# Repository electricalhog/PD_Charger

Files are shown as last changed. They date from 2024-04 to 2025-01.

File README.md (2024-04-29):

# PD_Charger

*Schematic*
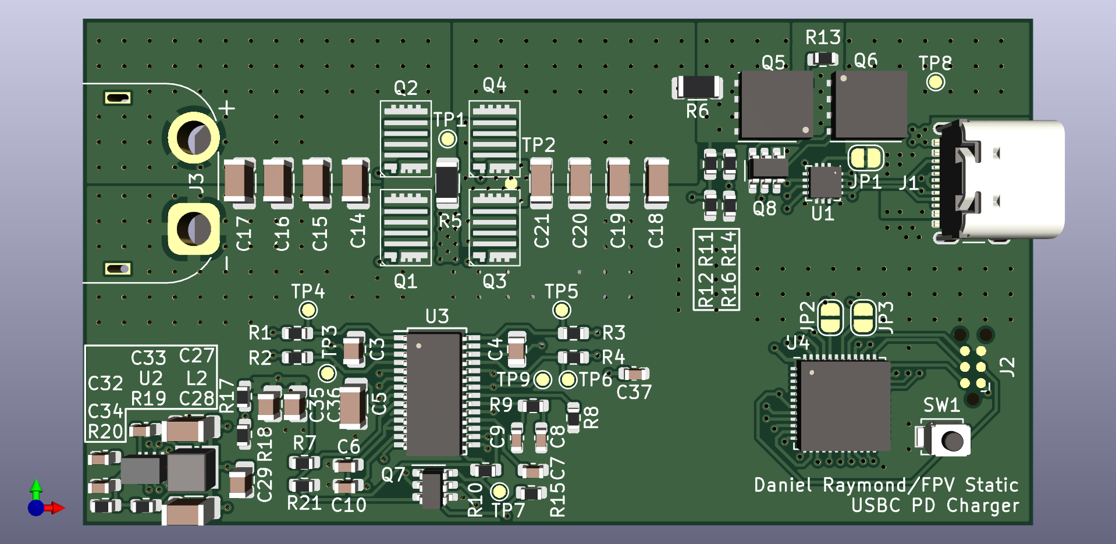
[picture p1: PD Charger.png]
PD Charger

*Board rendering*

[Digi-Key Cart](https://www.digikey.com/short/v39zppv0)

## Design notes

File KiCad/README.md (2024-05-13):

# PD_Charger
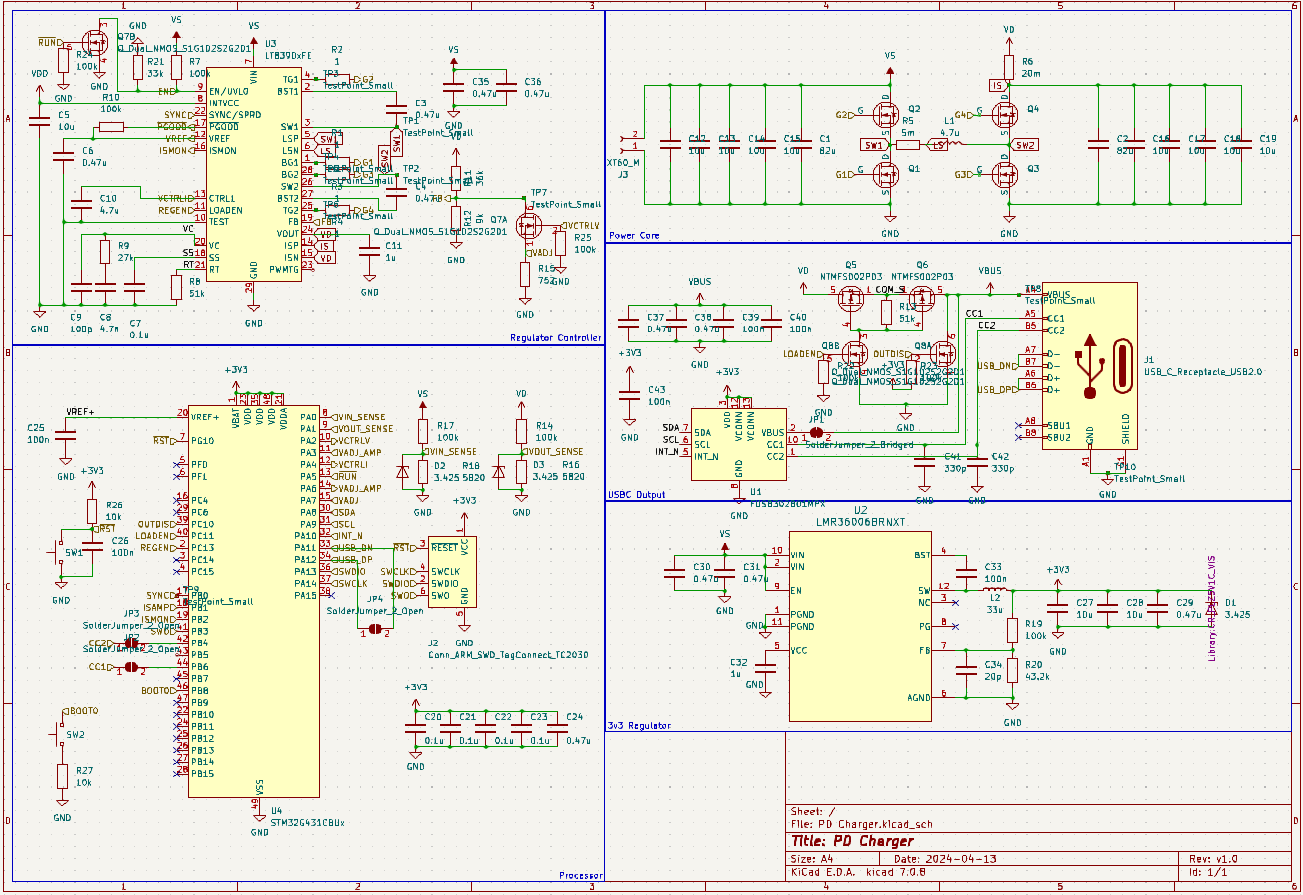
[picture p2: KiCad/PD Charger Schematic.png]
https://github.com/electricalhog/PD_Charger/blob/main/KiCad/PD%20Charger%20Schematic.png

*Schematic*
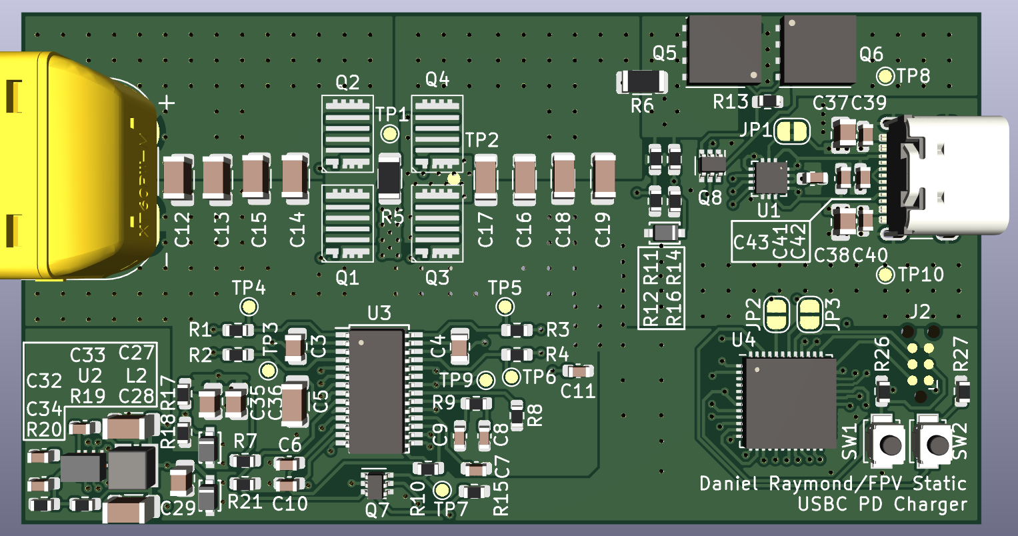
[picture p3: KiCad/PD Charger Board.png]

*Board rendering*

[Digi-Key Cart](https://www.digikey.com/short/v39zppv0)

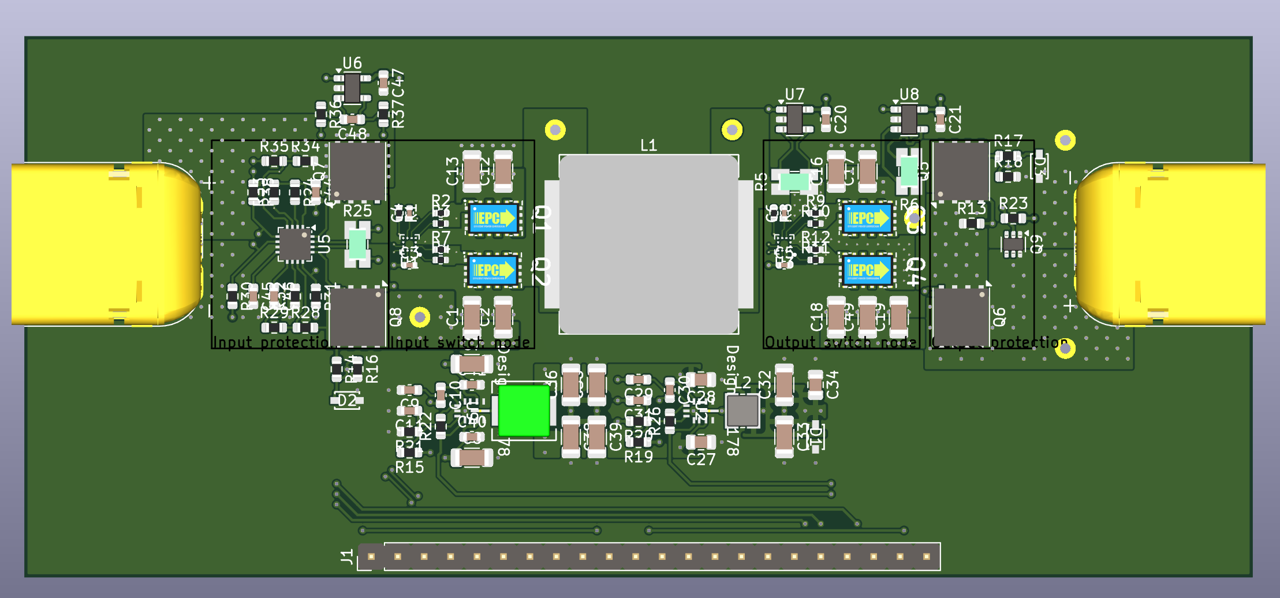
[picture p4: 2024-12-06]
KiCad/board.png

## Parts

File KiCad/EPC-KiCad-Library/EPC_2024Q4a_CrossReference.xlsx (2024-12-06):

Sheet: CrossRef
PART NUMBER | LandPattern Code | VALUE
EPC2001C | D0188 | 100V 7mE 36A
EPC2007C | D0199 | 100V 30mE 6A
EPC2010C | D0309 | 200V 25mE 22A
EPC2012C | D0375 | 200V 100mE 5A
EPC2014C | D0199 | 40V 16mE 10A
EPC2015C | D0188 | 40V 4mE 53A
EPC2016C | D0155 | 100V 16mE 18A
EPC2019 | D0364 | 200V 50mE 8.5A
EPC2020 | D0232 | 60V 2.2mE 90A
EPC2021 | D0232 | 80V 2.5mE 90A
EPC2022 | D0232 | 100V 3.2mE 90A
EPC2023 | D0232 | 30V 1.45mE 90A
EPC2024 | D0232 | 40V 1.5mE 90A
EPC2029 | D0386 | 80V 3.2mE 48A
EPC2030 | D0386 | 40V 2.4mE 48A
EPC2031 | D0386 | 60V 2.6mE 48A
EPC2032 | D0386 | 100V 4mE 48A
EPC2033 | D0386 | 150V 7mE 48A
EPC2034C | D0386 | 200V 8mE 48A
EPC2035 | D0353 | 60V 45mE 1.7A
EPC2036 | D0353 | 100V 73mE 1.7A
EPC2037 | D0353 | 100V 550mE 1.7A
EPC2038 | D0353 | 100V 3300mE 0.5A
EPC2039 | D0144 | 80V 25mE 6.8A
EPC2040 | D0210 | 15V 30mE 3.4A
EPC2044 | D0265 | 100V 9.4A 10.5mE
EPC2045 | D0012 | 100V 7mE 16A
EPC2050 | D0078 | 350V 65mE 6.3A
EPC2051 | D0001 | 100V 25mE 1.7A
EPC2052 | D0045 | 100V 13.5mE 8.2A
EPC2053 | D0034 | 100V 3.8mE 48A
EPC2054 | D0474 | 200V 32mE 2.4A
EPC2055 | D0133 | 40V 29A 3.6mE
EPC2057 | D0870 | 50V 8.5mE 6.9A
EPC2059 | D0298 | 170V 24A 6.8mE
EPC2065 | D0320 | 80 V 60A 3.6mE
EPC2066 | D0650 | 40V 1.1mE 90A
EPC2067 | D0540 | 40V 1.55mE 69A
EPC2069 | D0496 | 40V 2.25mE 80A
EPC2070 | D0562 | 100V 23mE 1.7A
EPC2071 | D0683 | 100V 2.2mE 64A
EPC2088 | D0320 | 100 V 60A 3.2mE
EPC2100 | D0342 | 30V 8.2mE/2.1mE 10A/40A 1:4HB
EPC2101 | D0342 | 60V 11.5mE/2.8mE 10A/40A 1:4HB
EPC2102 | D0342 | 60V 4.9mE 30A 1:1HB
EPC2103 | D0342 | 80V 5.5mE 30A 1:1HB
EPC2104 | D0342 | 100V 6.8mE 30A 1:1HB
EPC2105 | D0342 | 80V 14.5mE/3.6mE 10A/40A 1:4HB
EPC2106 | D0144 | 100V 70mE 1.7A 1:1HB
EPC2107 | D0144 | 100V 390mE 1.7A 1:1HB
EPC2108 | D0144 | 60V 240mE 1.7A 1:1HB
EPC2110 | D0144 | 120V 110mE 3.4A 1:1Common Source
EPC2111 | D0331 | 30 V HB 19mE/8mE 16A/16A 1:2HB
EPC2121 | D0826T44M | 100V 50mE 2.5A bi-directional
EPC2152 | D0122 | 80V, 12mE Sym HB IC with UVLO & ESDs.
EPC21601 | D0452 | 40V 10A eToF Laser Driver IC, 5V VDD 3.3V logic in
EPC21603 | D0452 | 40V 10A eToF Laser Driver IC, 5V VDD LVDS logic in
EPC21701 | D0617 | 80V 15A eToF Laser Driver IC, 3.3V VDD logic in
EPC2202 | D0155 | 80V 17mE 18A
EPC2203 | D0353 | 80V 80mE 1.7A
EPC2204 | D0133 | 100V 32A 6mE
EPC2204A | D0133 | 80V 29A 6mE
EPC2206 | D0232 | 80V 2.2mE 90A
EPC2207 | D0177 | 200V 22mE 22A
EPC2212 | D0155 | 100V 40mE 10A
EPC2214 | D0166 | 80V 20mE 10A
EPC2215 | D0111 | 200V 42A 8mE
EPC2216 | D0210 | 15V 26mE 3.4A
EPC2218 | D0320 | 100 V 60A 3.2mE
EPC2218A | D0320 | 80V 60A 3.2mE
EPC2219 | D0353 | 65 V, 3300mE, 0.5A
EPC2221 | D0551 | 100V 59mE 5A
EPC2234 | D0386 | 160V 8mE 48A
EPC2252 | D0045 | 100V 11mE 8.2A
EPC2302 | D0606F | 100V 101A 1.9mE
EPC2304 | D0606F | 200V 102 5mE
EPC2305 | D0606F | 150V 80A 3mE
EPC2306 | D0606H | 100V 48A 3.8mE
EPC2307 | D0606H | 200V 48A 10mE
EPC2308 | D0606H | 150V 48A 6mE
EPC23101 | D0629 | 100V, 2.7mE Upper FET HB driver IC with UVLO & ESDs.
EPC23102 | D0727 | 100V, 30A, 6.6mE Sym HB IC with UVLO & ESDs.
EPC23103 | D0727m | 100V, 30A, 8.3mE Sym HB IC with UVLO & ESDs.
EPC23104 | D0727u | 100V, 30A, 11mE Sym HB IC with UVLO & ESDs.
EPC2619 | D0133 | 80V 29A 4mE
EPC8002 | D0221 | 65V 480mE 2A
EPC8004 | D0221 | 40V 110mE 4A
EPC8009 | D0221 | 65V 130mE 4A
EPC8010 | D0221 | 100V 160mE 4A

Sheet: FootprintSummary
Unique Landpatterns
D0001
D0012
D0034
D0045
D0078
D0111
D0122
D0133
D0144
D0155
D0166
D0177
D0188
D0199
D0210
D0221
D0232
D0265
D0298
D0309
D0320
D0331
D0342
D0353
D0364
D0375
D0386
D0452
D0474
D0496
D0540
D0551
D0562
D0606F
D0606H
D0617
D0629
D0650
D0683
D0727
D0727m
D0727u
D0826T44M
D0870

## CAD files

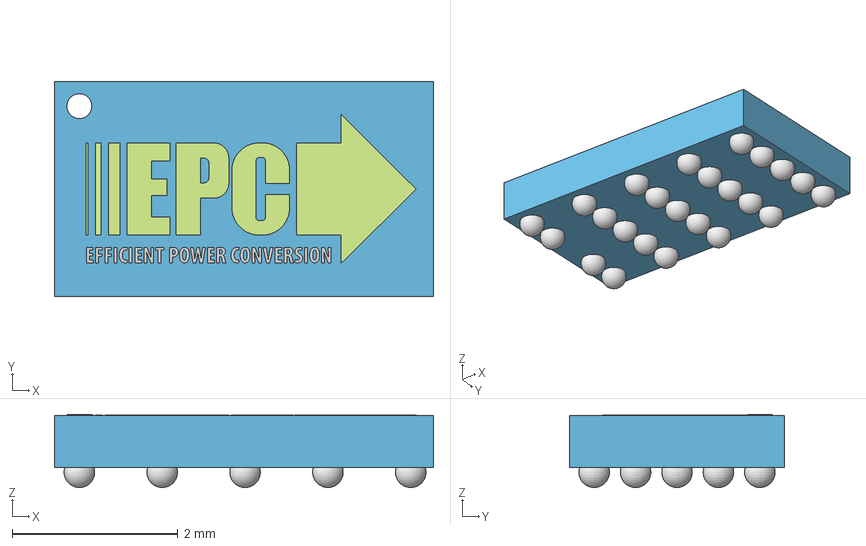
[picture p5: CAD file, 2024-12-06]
KiCad/EPC-KiCad-Library/Ki3DModels/D0386.step
4.57 x 2.60 x 0.882 mm
Green001
Green002
Green003
Green004
Green005
Green006
Green007
Extruded

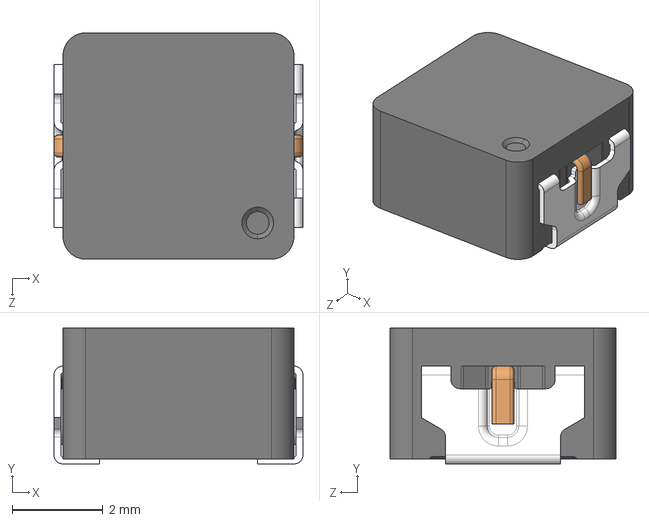
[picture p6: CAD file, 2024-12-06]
KiCad/ETQ_P3M100KVP/PCC-M0530M-LP.step
5.50 x 3.00 x 5.00 mm

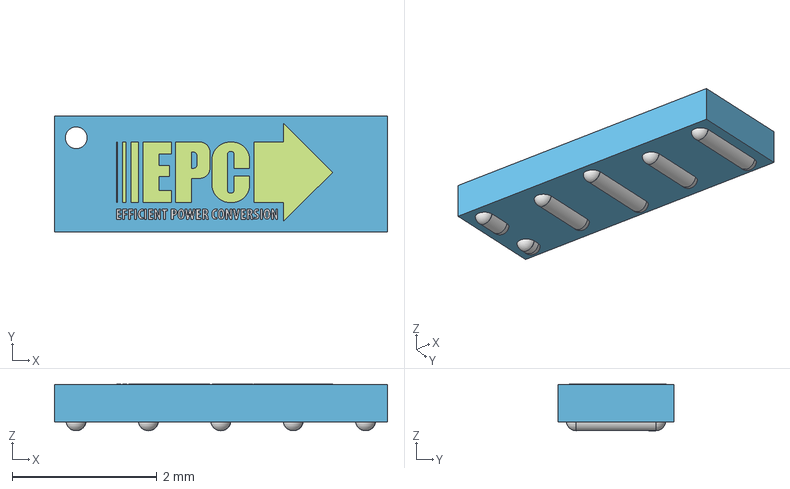
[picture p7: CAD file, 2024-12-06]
KiCad/EPC-KiCad-Library/Ki3DModels/D0111.step
4.60 x 1.60 x 0.642 mm
Green001
Green002
Green003
Green004
Green005
Green006
Green007
Extruded

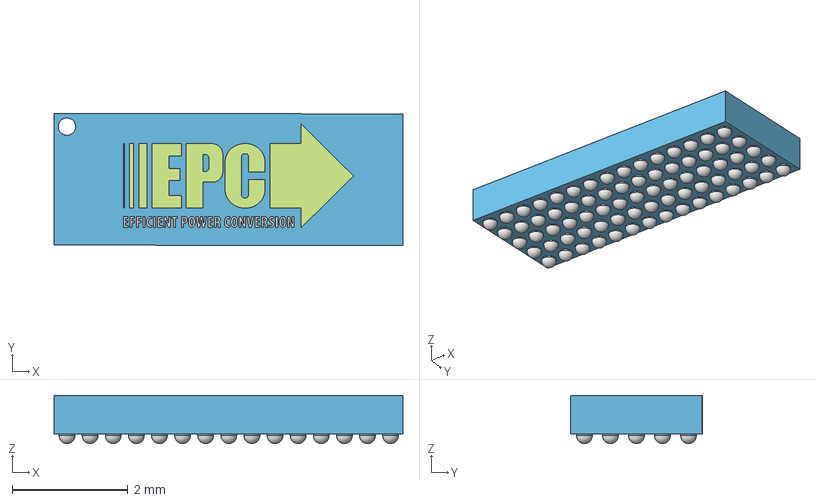
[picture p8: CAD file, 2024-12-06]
KiCad/EPC-KiCad-Library/Ki3DModels/D0342.step
6.04 x 2.29 x 0.832 mm
Green001
Green002
Green003
Green004
Green005
Green006
Green007
Extruded

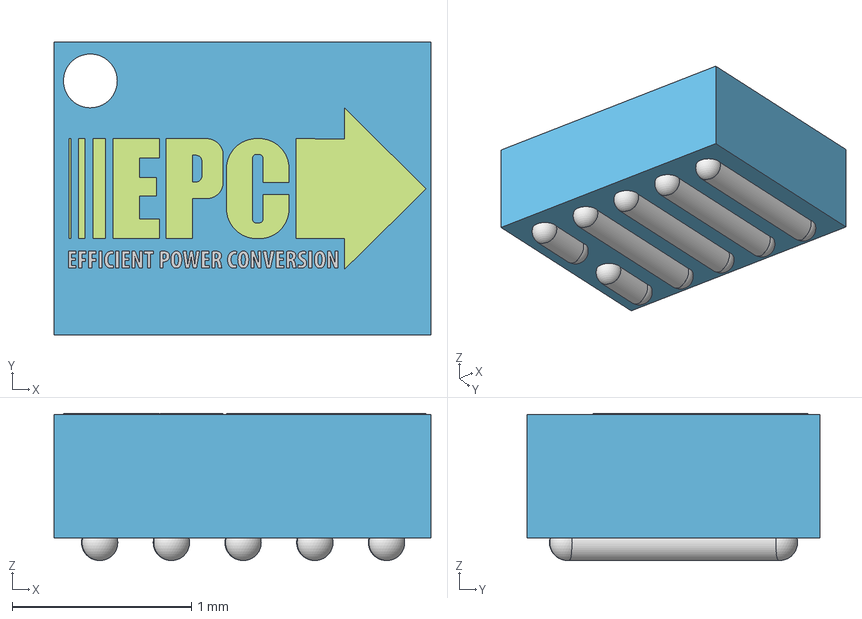
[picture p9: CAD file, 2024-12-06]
KiCad/EPC-KiCad-Library/Ki3DModels/D0155.step
2.10 x 1.63 x 0.82 mm
2mm
2mm001
2mm002
2mm003
2mm004
2mm005
2mm006
Extruded

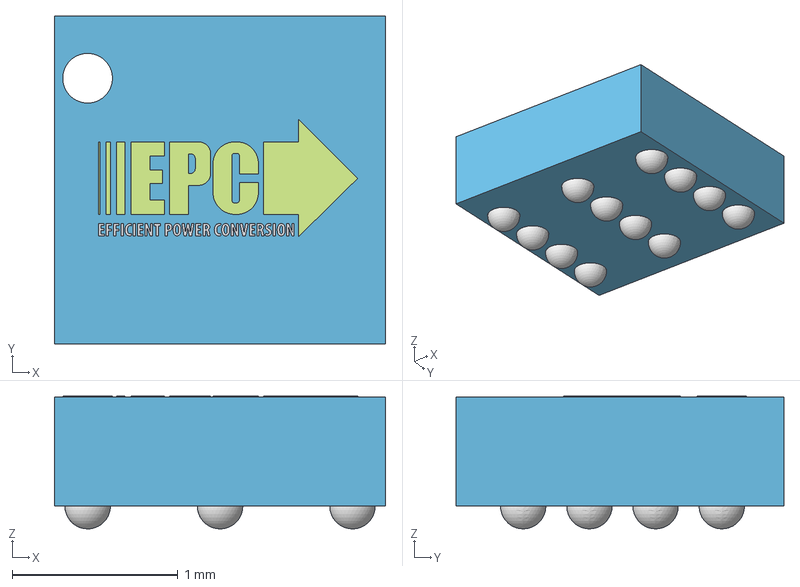
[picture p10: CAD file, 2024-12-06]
KiCad/EPC-KiCad-Library/Ki3DModels/D0078.step
2.00 x 1.98 x 0.803 mm
1.5mm
1.5mm001
1.5mm002
1.5mm003
1.5mm004
1.5mm005
1.5mm006
Extruded

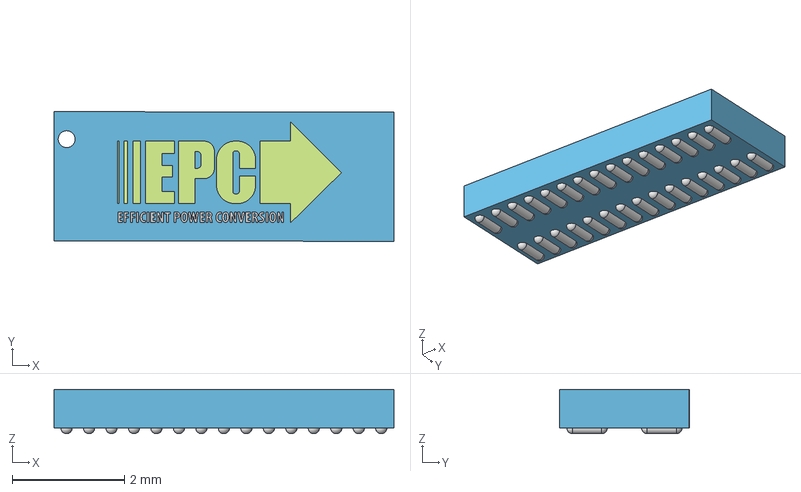
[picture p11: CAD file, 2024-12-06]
KiCad/EPC-KiCad-Library/Ki3DModels/D0232.step
6.05 x 2.31 x 0.79 mm
Green001
Green002
Green003
Green004
Green005
Green006
Green007
Extruded

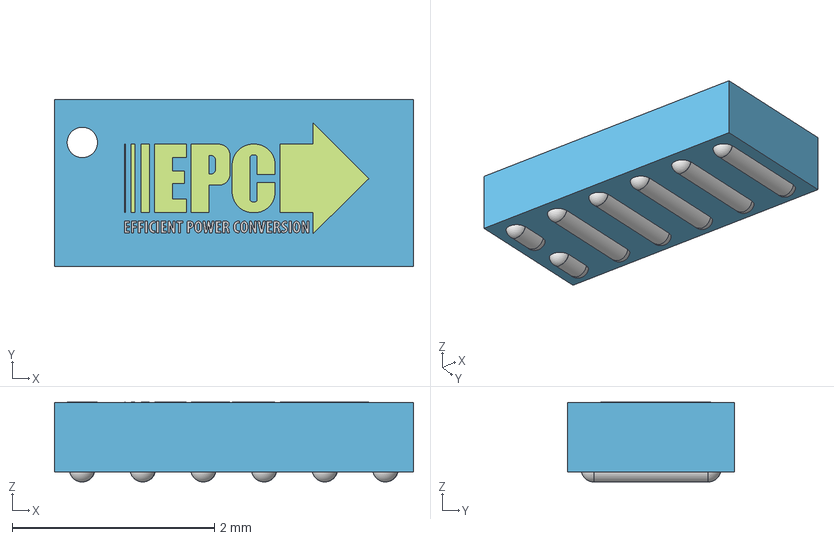
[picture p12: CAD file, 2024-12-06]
KiCad/EPC-KiCad-Library/Ki3DModels/D0309.step
3.55 x 1.65 x 0.79 mm
2.5mm
2.5mm001
2.5mm002
2.5mm003
2.5mm004
2.5mm005
2.5mm006
Extruded

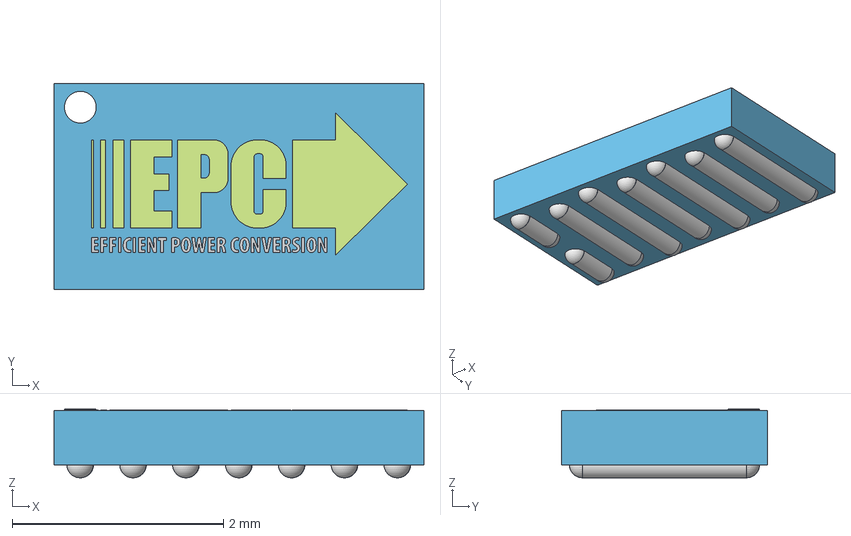
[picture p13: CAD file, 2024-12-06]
KiCad/EPC-KiCad-Library/Ki3DModels/D0320.step
3.50 x 1.95 x 0.65 mm
Green001
Green002
Green003
Green004
Green005
Green006
Green007
Extruded

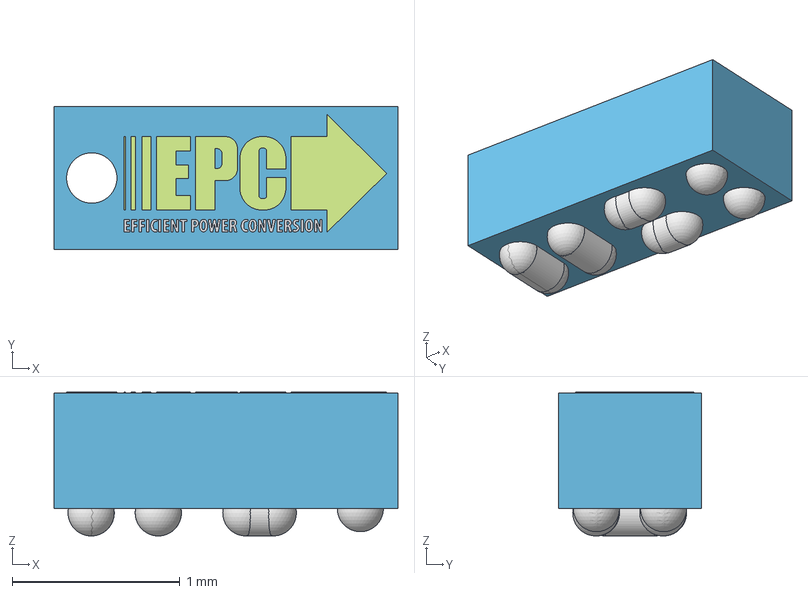
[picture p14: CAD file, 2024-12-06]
KiCad/EPC-KiCad-Library/Ki3DModels/D0221.step
2.05 x 0.85 x 0.858 mm
1.5mm
1.5mm001
1.5mm002
1.5mm003
1.5mm004
1.5mm005
1.5mm006
Extruded

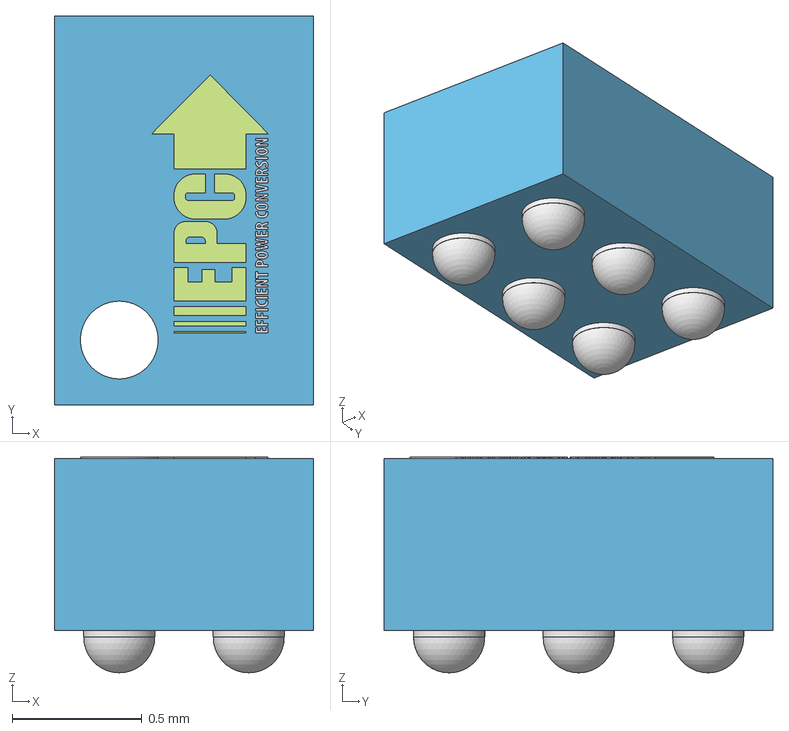
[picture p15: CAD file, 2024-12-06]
KiCad/EPC-KiCad-Library/Ki3DModels/D0452.step
1 x 1.50 x 0.833 mm
1mm
1mm001
1mm002
1mm003
1mm004
1mm005
1mm006
Extruded

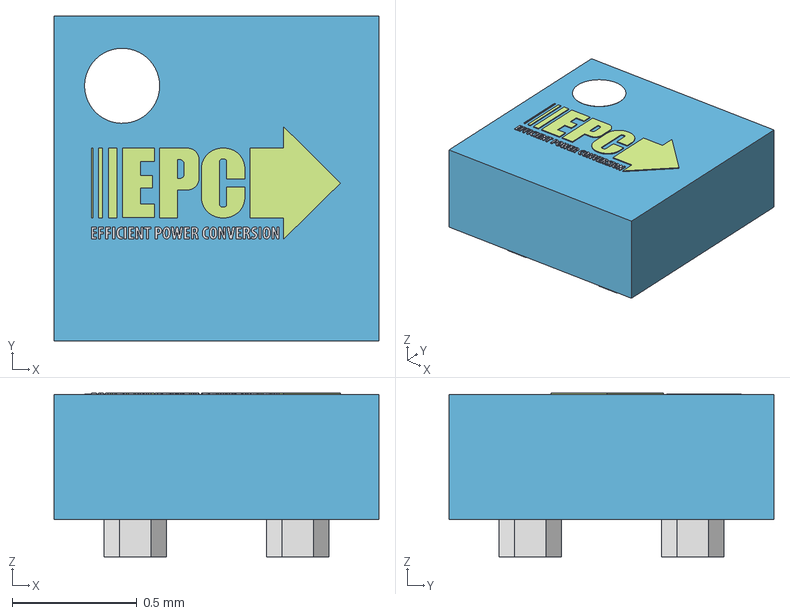
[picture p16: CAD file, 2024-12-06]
KiCad/EPC-KiCad-Library/Ki3DModels/D0474.step
1.30 x 1.30 x 0.655 mm
1mm
1mm001
1mm002
1mm003
1mm004
1mm005
1mm006
Extruded x 4
Extruded004

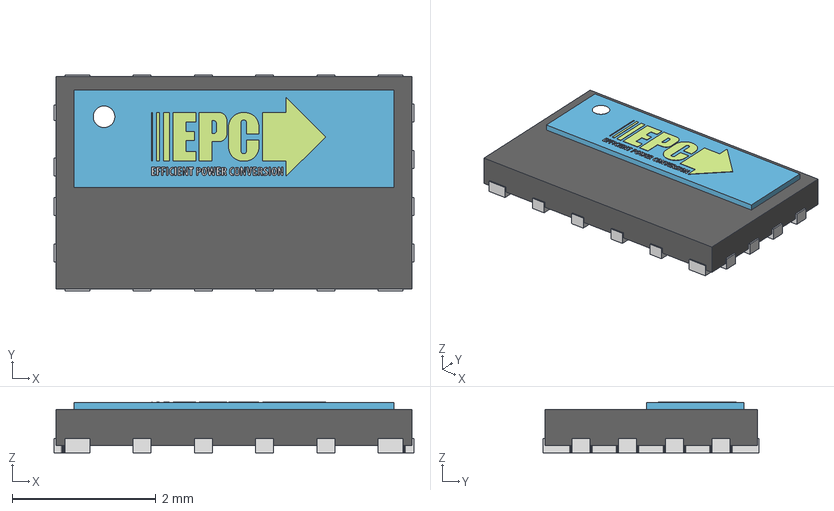
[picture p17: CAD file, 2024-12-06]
KiCad/EPC-KiCad-Library/Ki3DModels/D0606H.step
5.00 x 3.00 x 0.705 mm
2.5mm
2.5mm001
2.5mm002
2.5mm003
2.5mm004
2.5mm005
2.5mm006
Extruded
Extruded001
Extruded002
Extruded003
Extruded004 x 4
Extruded008

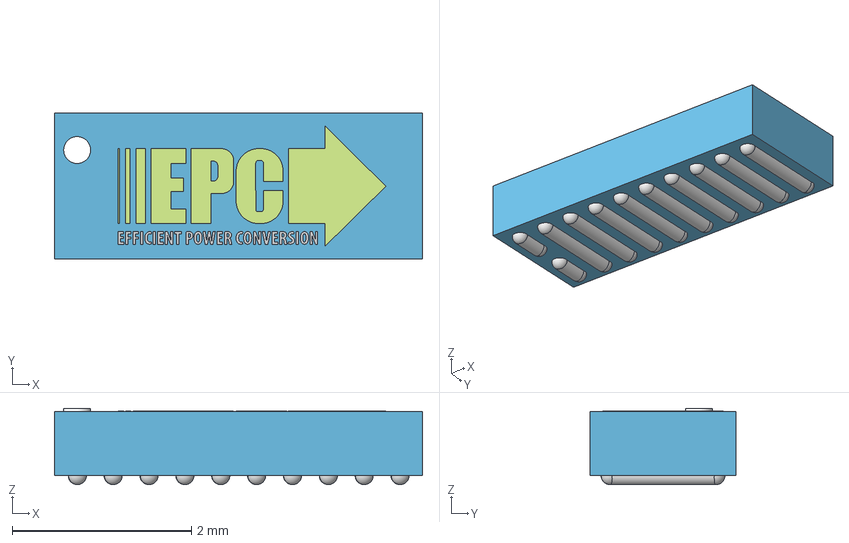
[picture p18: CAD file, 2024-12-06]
KiCad/EPC-KiCad-Library/Ki3DModels/D0188.step
4.11 x 1.63 x 0.85 mm
Green001
Green002
Green003
Green004
Green005
Green006
Green007
Extruded

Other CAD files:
KiCad/EPC-KiCad-Library/Ki3DModels/D0441.step
KiCad/EPC-KiCad-Library/Ki3DModels/D0375.step
KiCad/EPC-KiCad-Library/Ki3DModels/D0551.step
KiCad/EPC-KiCad-Library/Ki3DModels/D0683.step
KiCad/EPC-KiCad-Library/Ki3DModels/D0001.step
KiCad/EPC-KiCad-Library/Ki3DModels/D0012.step
KiCad/EPC-KiCad-Library/Ki3DModels/D0034.step
KiCad/EPC-KiCad-Library/Ki3DModels/D0045.step
KiCad/EPC-KiCad-Library/Ki3DModels/D0122.step
KiCad/EPC-KiCad-Library/Ki3DModels/D0133.step
KiCad/EPC-KiCad-Library/Ki3DModels/D0144.step
KiCad/EPC-KiCad-Library/Ki3DModels/D0166.step
KiCad/EPC-KiCad-Library/Ki3DModels/D0177.step
KiCad/EPC-KiCad-Library/Ki3DModels/D0199.step
KiCad/EPC-KiCad-Library/Ki3DModels/D0210.step
KiCad/EPC-KiCad-Library/Ki3DModels/D0265.step
KiCad/EPC-KiCad-Library/Ki3DModels/D0298.step
KiCad/EPC-KiCad-Library/Ki3DModels/D0331.step
KiCad/EPC-KiCad-Library/Ki3DModels/D0353.step
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

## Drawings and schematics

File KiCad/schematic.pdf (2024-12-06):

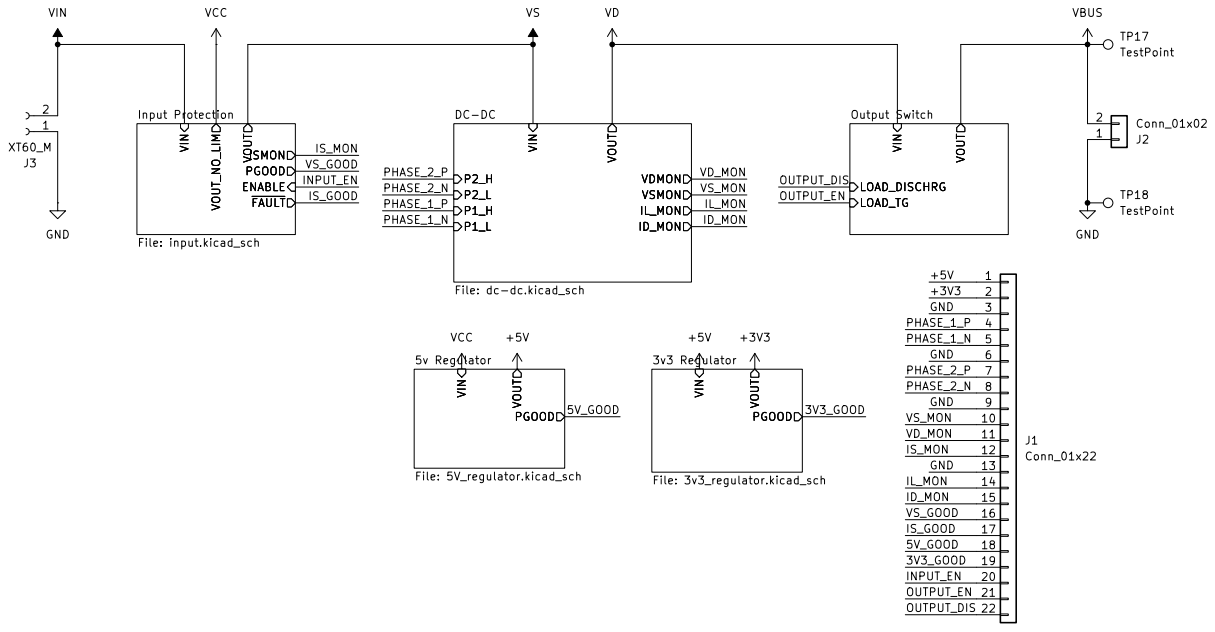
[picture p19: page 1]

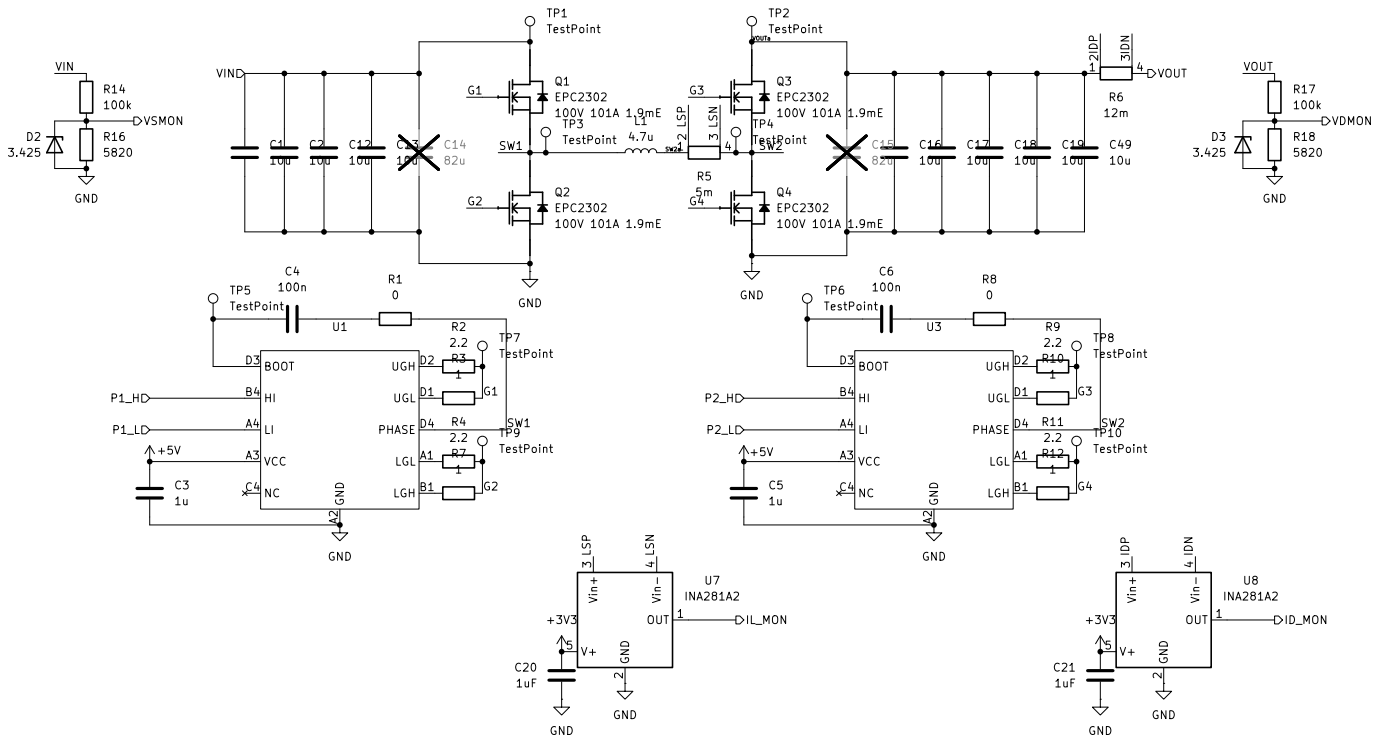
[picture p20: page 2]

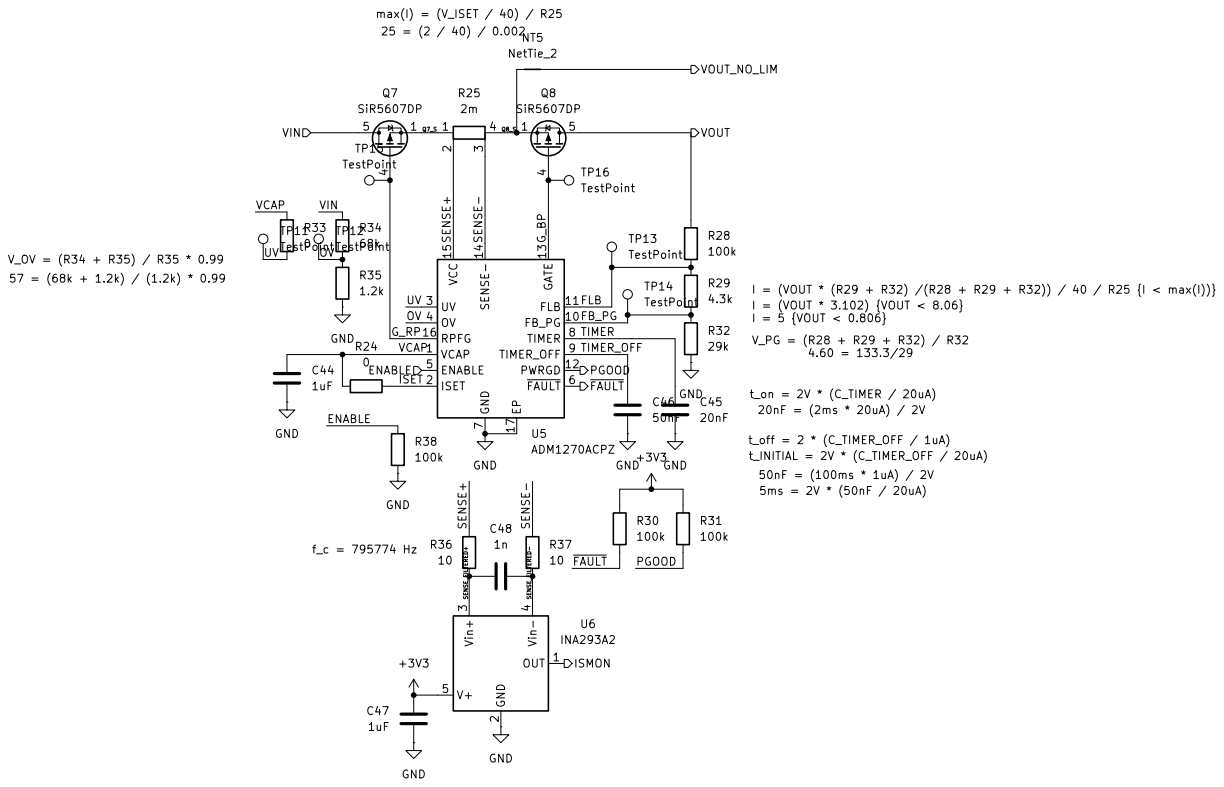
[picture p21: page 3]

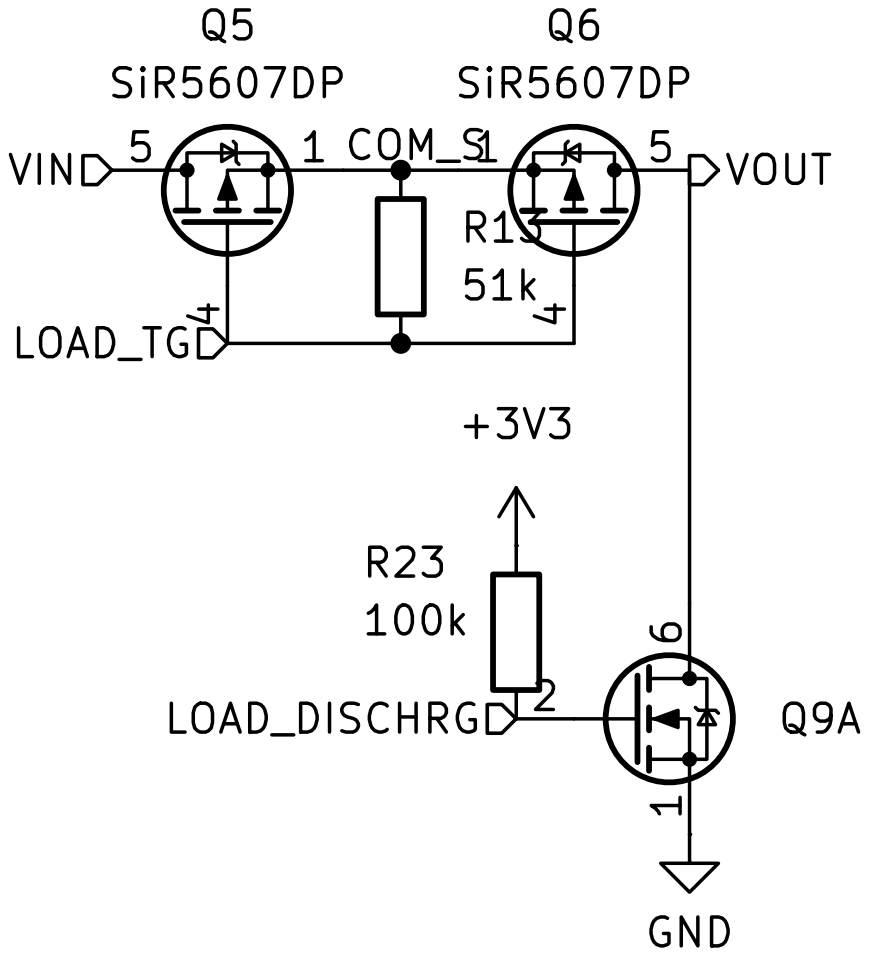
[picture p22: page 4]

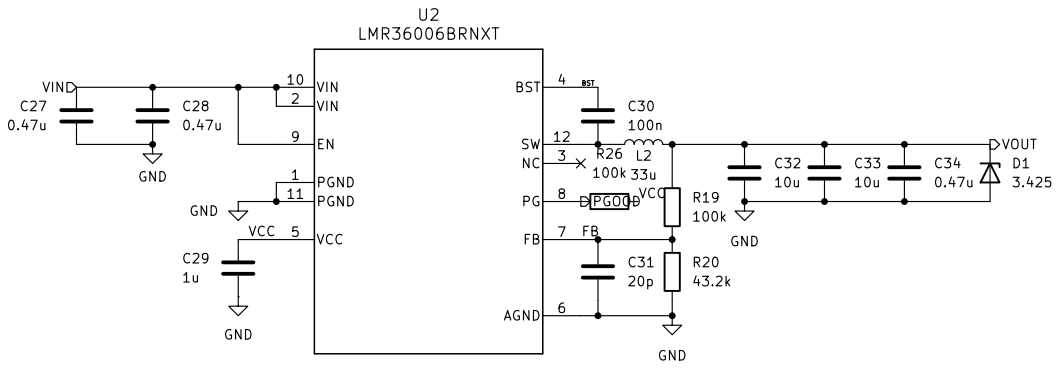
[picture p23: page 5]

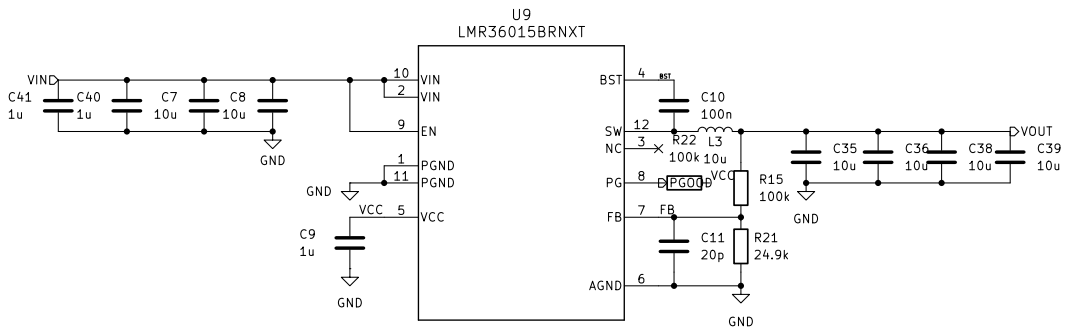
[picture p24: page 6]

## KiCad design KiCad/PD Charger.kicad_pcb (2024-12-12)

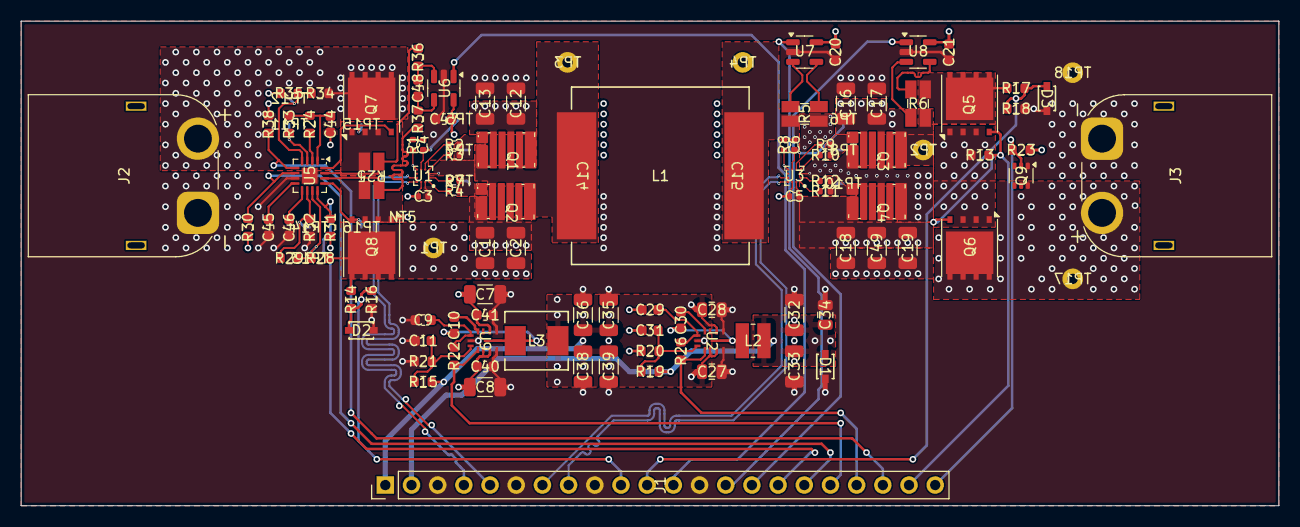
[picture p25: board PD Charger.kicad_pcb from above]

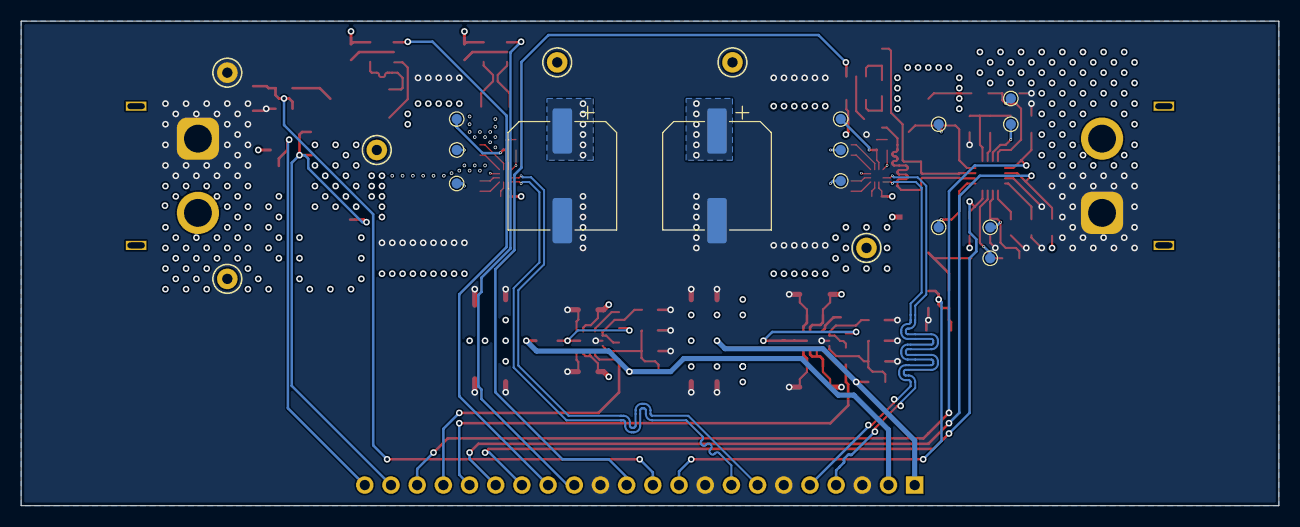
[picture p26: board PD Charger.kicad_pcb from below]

Board: 4 copper layers, 122.0 x 47.0 mm, 123 parts (20 on the bottom side), 73 nets.

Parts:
C1, C2, C7, C8, C12, C13, C16, C17, C18, C19, C32, C33, C35, C36, C38, C39, C49: 10u; C_1206_3216Metric
C3, C5: 1u; C_0402_1005Metric
C4, C6: 100n; C_0402_1005Metric
C9, C29, C40, C41: 1u; C_0603_1608Metric
C10, C30: 100n; C_0603_1608Metric
C11, C31: 20p; C_0603_1608Metric
C14, C15: 82u; CP_Elec_10x7.9
C20, C21, C44, C47: 1uF; C_0603_1608Metric
C27, C28, C34: 0.47u; C_0805_2012Metric
C45: 20nF; C_0603_1608Metric
C46: 50nF; C_0603_1608Metric
C48: 1n; C_0603_1608Metric
D1, D2, D3: 3.425; CR_PLZ5V1C_VIS
J1: Conn_01x22; PinHeader_1x22_P2.54mm_Vertical
J2, J3: XT60_M; AMASS_XT60PW-M_1x02_P7.20mm_Horizontal
L1: 4.7u; L_Vishay_IHLP-6767
L2: 33u; L_Wuerth_MAPI-3015
L3: 10u; IND_PCC-M0530M-LP_PAN
NT5: NetTie_2; NetTie-2_SMD_Pad0.5mm
Q1, Q2, Q3, Q4: EPC2302; D0606F_100V
Q5, Q6, Q7, Q8: SiR5607DP; AO_DFN-8-1EP_5.55x5.2mm_P1.27mm_EP4.12x4.6mm
Q9: Q_Dual_NMOS_S1G1D2S2G2D1; SOT-363_SC-70-6
R1, R8: 0; R_0402_1005Metric
R2, R4, R9, R11: 2.2; R_0402_1005Metric
R3, R7, R10, R12: 1; R_0402_1005Metric
R5: 5m; R_Shunt_Ohmite_LVK12
R6: 12m; R_Shunt_Ohmite_LVK12
R13: 51k; R_0603_1608Metric
R14, R15, R17, R19, R22, R23, R26, R28, R30, R31, R38: 100k; R_0603_1608Metric
R16, R18: 5820; R_0603_1608Metric
R20: 43.2k; R_0603_1608Metric
R21: 24.9k; R_0603_1608Metric
R24, R33: 0; R_0603_1608Metric
R25: 2m; R_Shunt_Ohmite_LVK12
R29: 4.3k; R_0603_1608Metric
R32: 29k; R_0603_1608Metric
R34: 68k; R_0603_1608Metric
R35: 1.2k; R_0603_1608Metric
R36, R37: 10; R_0603_1608Metric
TP1, TP2, TP3, TP4, TP17, TP18: TestPoint; TestPoint_Keystone_5000-5004_Miniature
TP5, TP6, TP7, TP8, TP9, TP10, TP11, TP12, TP13, TP14, TP15, TP16: TestPoint; TestPoint_Pad_D1.0mm
U1, U3: WLCSP1.6x1.6-12B
U2: LMR36006BRNXT; RNX0012B
U5: ADM1270ACPZ; LFCSP-16-1EP_3x3mm_P0.5mm_EP1.5x1.5mm
U6: INA293A2; SOT-23-5
U7, U8: INA281A2; SOT-23-5
U9: LMR36015BRNXT; RNX0012B

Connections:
+3V3: C20.1, C21.1, C32.1, C33.1, C34.2, C47.1, D1.1 (K), J1.2, L2.2, R19.1, R23.2, R30.2, R31.2, U6.5 (V+), U7.5 (V+), U8.5 (V+)
+5V: C3.1, C5.1, C27.2, C28.2, C35.1, C36.1, C38.1, C39.1, J1.1, L3.2, R15.1, U1.A3 (VCC), U2.2 (VIN), U2.9 (EN), U2.10 (VIN), U3.A3 (VCC)
/3V3_GOOD: J1.19, R26.1, U2.8 (PG)
/3v3 Regulator/BST: C30.1, U2.4 (BST)
/3v3 Regulator/FB: C31.1, R19.2, R20.1, U2.7 (FB)
/3v3 Regulator/VCC: C29.1, R26.2, U2.5 (VCC)
/5V_GOOD: J1.18, R22.1, U9.8 (PG)
/5v Regulator/BST: C10.1, U9.4 (BST)
/5v Regulator/FB: C11.1, R15.2, R21.1, U9.7 (FB)
/5v Regulator/VCC: C9.1, R22.2, U9.5 (VCC)
/DC-DC/G1: Q1.1 (G), R2.2, R3.2, TP7.1
/DC-DC/G2: Q2.1 (G), R4.2, R7.2, TP9.1
/DC-DC/G3: Q3.1 (G), R9.2, R10.2, TP8.1
/DC-DC/G4: Q4.1 (G), R11.2, R12.2, TP10.1
/DC-DC/IDN: R6.3, U8.4 (Vin-)
/DC-DC/IDP: R6.2, U8.3 (Vin+)
/DC-DC/LSN: R5.3, U7.4 (Vin-)
/DC-DC/LSP: R5.2, U7.3 (Vin+)
/DC-DC/SW1: L1.1, Q1.2 (S), Q1.4 (S), Q1.6 (S), Q2.3 (D), Q2.5 (D), Q2.7 (D), R1.2, TP3.1, U1.C1 (PHASE), U1.D4 (PHASE)
/DC-DC/SW2: Q3.2 (S), Q3.4 (S), Q3.6 (S), Q4.3 (D), Q4.5 (D), Q4.7 (D), R5.4, R8.2, U3.C1 (PHASE), U3.D4 (PHASE)
/DC-DC/SW2a: L1.2, R5.1
/DC-DC/VOUTa: C15.1, C16.1, C17.1, C18.1, C19.1, C49.1, Q3.3 (D), Q3.5 (D), Q3.7 (D), R6.1, TP2.1
/ID_MON: J1.15, U8.1 (OUT)
/IL_MON: J1.14, U7.1 (OUT)
/INPUT_EN: J1.20, R38.2, U5.5 (ENABLE)
/IS_GOOD: J1.17, R30.1, U5.6 (~FAULT)
/IS_MON: J1.12, U6.1 (OUT)
/Input Protection/FB_PG: R29.1, R32.2, TP14.1, U5.10 (FB_PG)
/Input Protection/FLB: R28.1, R29.2, TP13.1, U5.11 (FLB)
/Input Protection/G_BP: Q8.4 (G), TP16.1, U5.13 (GATE)
/Input Protection/G_RP: Q7.4 (G), TP15.1, U5.16 (RPFG)
/Input Protection/ISET: R24.2, U5.2 (ISET)
/Input Protection/OV: R34.1, R35.2, TP12.1, U5.4 (OV)
/Input Protection/Q7_S: Q7.1 (S), Q7.2 (S), Q7.3 (S), R25.1
/Input Protection/Q8_S: NT5.2, Q8.1 (S), Q8.2 (S), Q8.3 (S), R25.4
/Input Protection/SENSE+: R25.2, R36.2, U5.15 (VCC)
/Input Protection/SENSE-: R25.3, R37.2, U5.14 (SENSE-)
/Input Protection/SENSE_FILTERED+: C48.2, R36.1, U6.3 (Vin+)
/Input Protection/SENSE_FILTERED-: C48.1, R37.1, U6.4 (Vin-)
/Input Protection/TIMER: C45.1, U5.8 (TIMER)
/Input Protection/TIMER_OFF: C46.1, U5.9 (TIMER_OFF)
/Input Protection/UV: R33.1, TP11.1, U5.3 (UV)
/Input Protection/VCAP: C44.1, R24.1, R33.2, U5.1 (VCAP)
/OUTPUT_DIS: J1.22, Q9.2 (G), R23.1
/OUTPUT_EN: J1.21, Q5.4 (G), Q6.4 (G), R13.2
/Output Switch/COM_S: Q5.1 (S), Q5.2 (S), Q5.3 (S), Q6.1 (S), Q6.2 (S), Q6.3 (S), R13.1
/PHASE_1_N: J1.5, U1.A4 (LI)
/PHASE_1_P: J1.4, U1.B4 (HI)
/PHASE_2_N: J1.8, U3.A4 (LI)
/PHASE_2_P: J1.7, U3.B4 (HI)
/VD_MON: D3.1 (K), J1.11, R17.2, R18.1
/VS_GOOD: J1.16, R31.1, U5.12 (PWRGD)
/VS_MON: D2.1 (K), J1.10, R14.2, R16.1
GND: C1.2, C2.2, C3.2, C5.2, C7.2, C8.2, C9.2, C11.2, C12.2, C13.2, C14.2, C15.2, C16.2, C17.2, C18.2, C19.2, C20.2, C21.2, C27.1, C28.1, C29.2, C31.2, C32.2, C33.2, C34.1, C35.2, C36.2, C38.2, C39.2, C40.2, C41.2, C44.2, C45.2, C46.2, C47.2, C49.2, D1.2 (A), D2.2 (A), D3.2 (A), J1.3, J1.6, J1.9, J1.13, J2.1, J3.1, Q2.2 (S), Q2.4 (S), Q2.6 (S), Q4.2 (S), Q4.4 (S), Q4.6 (S), Q9.1 (S), R16.2, R18.2, R20.2, R21.2, R32.1, R35.1, R38.1, TP18.1, U1.A2 (GND), U2.1 (PGND), U2.6 (AGND), U2.11 (PGND), U3.A2 (GND), U5.7 (GND), U5.17 (EP), U6.2 (GND), U7.2 (GND), U8.2 (GND), U9.1 (PGND), U9.6 (AGND), U9.11 (PGND)
unnamed: C4.2, R1.1
unnamed: C6.2, R8.1
unnamed: C4.1, TP5.1, U1.D3 (BOOT)
unnamed: R7.1, U1.B1 (LGH)
unnamed: R4.1, U1.A1 (LGL)
unnamed: R2.1, U1.D2 (UGH)
unnamed: R3.1, U1.D1 (UGL)
unnamed: C30.2, L2.1, U2.12 (SW)
unnamed: C6.1, TP6.1, U3.D3 (BOOT)
unnamed: R12.1, U3.B1 (LGH)
unnamed: R11.1, U3.A1 (LGL)
unnamed: R9.1, U3.D2 (UGH)
unnamed: R10.1, U3.D1 (UGL)
unnamed: C10.2, L3.1, U9.12 (SW)
VBUS: J3.2, Q6.5 (D), Q9.6 (D), TP17.1
VCC: C7.1, C8.1, C40.1, C41.1, NT5.1, U9.2 (VIN), U9.9 (EN), U9.10 (VIN)
VD: Q5.5 (D), R6.4, R17.1
VIN: J2.2, Q7.5 (D), R34.2
VS: C1.1, C2.1, C12.1, C13.1, C14.1, Q1.3 (D), Q1.5 (D), Q1.7 (D), Q8.5 (D), R14.1, R28.2, TP1.1

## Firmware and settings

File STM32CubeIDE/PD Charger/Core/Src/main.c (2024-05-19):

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
/* Includes ------------------------------------------------------------------*/
#include "main.h"

ADC_HandleTypeDef hadc1;
ADC_HandleTypeDef hadc2;

DAC_HandleTypeDef hdac1;
DAC_HandleTypeDef hdac3;

I2C_HandleTypeDef hi2c2;

OPAMP_HandleTypeDef hopamp1;
OPAMP_HandleTypeDef hopamp2;
OPAMP_HandleTypeDef hopamp3;

TIM_HandleTypeDef htim3;

PCD_HandleTypeDef hpcd_USB_FS;

/* USER CODE BEGIN PV */
static double volts;
static double amps;
static uint32_t DAC_volts;
static uint32_t DAC_amps;
const int slew_volts = 1; // multiples of 12mV/us
const int slew_amps = 1; //multiples of 2.4mA/us
static char voltage_set;
static char current_set;
/* USER CODE END PV */

void SystemClock_Config(void);
static void MX_GPIO_Init(void);
static void MX_DAC1_Init(void);
static void MX_USB_PCD_Init(void);
static void MX_DAC3_Init(void);
static void MX_OPAMP3_Init(void);
static void MX_OPAMP1_Init(void);
static void MX_ADC1_Init(void);
static void MX_ADC2_Init(void);
static void MX_OPAMP2_Init(void);
static void MX_TIM3_Init(void);
static void MX_I2C2_Init(void);
static void MX_UCPD1_Init(void);
/* USER CODE BEGIN PFP */
void HAL_TIM_PeriodElapsedCallback(TIM_HandleTypeDef *htim);
static int DAC_Voltage(double voltage);
static void setVoltage(double voltage);
static int DAC_Current(double current);
static void setCurrent(double current);
/* USER CODE END PFP */

/* USER CODE BEGIN 0 */
static void setVoltage(double voltage){
	voltage_set = 0;
	volts = voltage; // save local value to global for safe-keeping
	DAC_volts = HAL_DAC_GetValue(&hdac3, DAC_CHANNEL_1); // save starting condition from DAC
	HAL_TIM_Base_Start_IT(&htim3);
}

static void setCurrent(double current){
	current_set = 0;
	amps = current; // save local value to global for safe-keeping
	DAC_amps = HAL_DAC_GetValue(&hdac1, DAC_CHANNEL_1); // save starting condition from DAC
	HAL_TIM_Base_Start_IT(&htim3);
}

static int DAC_Voltage(double voltage){ // voltage to DAC scaling function
	int v = (int)(voltage-5.2733)/0.0119755;
	return (v>0) ? v : 0;
}

static int DAC_Current(double current){ // current to DAC scaling function
	int c = (int)((current*0.02*10)+0.25)*(4095/2);
	return (c>0) ? c : 0;
}

void HAL_TIM_PeriodElapsedCallback(TIM_HandleTypeDef *htim)
{
  if (htim->Instance == TIM3) // 1us ISR for soft-slewing
  {
	if(voltage_set != 1) // voltage soft-slew active
	{
      if (DAC_volts < DAC_Voltage(volts)) // has not reached set-point
      {
      	DAC_volts += slew_volts; // increment by constant
      	HAL_DAC_SetValue(&hdac3, DAC_CHANNEL_1, DAC_ALIGN_12B_R, DAC_volts); // write to DAC
      }
      else
      {
      	voltage_set = 1;
      }
	}
	if(current_set != 1) // current soft-slew active
	{
      if (DAC_amps < DAC_Current(amps)) // has not reached set-point
      {
      	DAC_amps += slew_amps; // increment by constant
      	HAL_DAC_SetValue(&hdac1, DAC_CHANNEL_1, DAC_ALIGN_12B_R, DAC_amps); // write to DAC
      }
      else
      {
      	current_set = 1;
      }
	}
	if (current_set && voltage_set) // soft-slew complete
	{
		HAL_TIM_Base_Stop_IT(&htim3); // turn of timer
	}
  }
}
/* USER CODE END 0 */

/**
  * @brief  The application entry point.
  * @retval int
  */
int main(void)
{

  /* MCU Configuration--------------------------------------------------------*/

  /* Reset of all peripherals, Initializes the Flash interface and the Systick. */
  HAL_Init();

  /* Configure the system clock */
  SystemClock_Config();

  /* Initialize all configured peripherals */
  MX_GPIO_Init();
  MX_DAC1_Init();
  MX_USB_PCD_Init();
  MX_DAC3_Init();
  MX_OPAMP3_Init();
  MX_OPAMP1_Init();
  MX_ADC1_Init();
  MX_ADC2_Init();
  MX_OPAMP2_Init();
  MX_TIM3_Init();
  MX_I2C2_Init();
  MX_UCPD1_Init();
  /* USER CODE BEGIN 2 */

  HAL_DAC_Start(&hdac1, DAC_CHANNEL_1);
  HAL_DAC_Start(&hdac3, DAC_CHANNEL_1);
  HAL_OPAMP_Start(&hopamp1);
  HAL_OPAMP_Start(&hopamp2);
  HAL_OPAMP_Start(&hopamp3);


  HAL_GPIO_WritePin(Run_GPIO_Port, Run_Pin, SET);
  HAL_GPIO_WritePin(SYNC_GPIO_Port, SYNC_Pin, RESET);
  HAL_GPIO_WritePin(Discharge_GPIO_Port, Discharge_Pin, SET);
  HAL_GPIO_WritePin(Enable_GPIO_Port, Enable_Pin, RESET);


  HAL_Delay(2500);
  setCurrent(3);
  while(!current_set);
  HAL_Delay(2500);
  setCurrent(5);
  while(!current_set);


  /* USER CODE END 2 */

  /* Infinite loop */
  /* USER CODE BEGIN WHILE */
  while (1)
  {
    /* USER CODE END WHILE */

    /* USER CODE BEGIN 3 */
  }
  /* USER CODE END 3 */
}

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


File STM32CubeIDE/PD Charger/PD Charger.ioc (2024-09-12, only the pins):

Mcu.UserName=STM32G431C6Ux
PA0.Signal=COMP1_INM
PA1.Signal=COMP1_INP
PA10.GPIO_Label=INT_N
PA10.Signal=GPXTI10
PA13.Signal=SYS_JTMS-SWDIO
PA14.Signal=SYS_JTCK-SWCLK
PA2.Signal=LPUART1_TX
PA3.Signal=LPUART1_RX
PA4.GPIO_Label=VCTRL
PA4.Signal=COMP_DAC11_group
PA5.GPIO_Label=ICTRL
PA5.Signal=COMP_DAC12_group
PA6.GPIO_Label=VDMON
PA6.Signal=ADC2_IN3
PA7.GPIO_Label=IDMON
PA7.Signal=ADC2_IN4
PA8.Signal=I2C2_SDA
PA9.Signal=I2C2_SCL
PB0.Signal=OPAMP3_VINP
PB1.Signal=OPAMP3_VOUT
PB11.GPIO_Label=ISMON
PB11.Signal=ADC1_IN14
PB12.GPIO_Label=REG_ON
PB12.Signal=GPIO_Input
PB13.GPIO_Label=PGOOD_N
PB13.Signal=GPIO_Input
PB14.GPIO_Label=SGOOD
PB14.Signal=GPIO_Input
PB15.GPIO_Label=FAULT_N
PB15.Signal=GPIO_Input
PB2.Signal=OPAMP3_VINM
PB4.Signal=UCPD1_CC2
PB6.Signal=UCPD1_CC1
PB9.GPIO_Label=SYNC
PB9.Signal=S_TIM17_CH1
PC13.GPIO_Label=LOAD_DISCHRG
PC13.Signal=GPIO_Output
PC14-OSC32_IN.GPIO_Label=LOAD_EN
PC14-OSC32_IN.Signal=GPIO_Output
PC15-OSC32_OUT.GPIO_Label=ENABLE
PC15-OSC32_OUT.Signal=GPIO_Output
PC4.GPIO_Label=VSMON
PC4.Signal=ADC2_IN5

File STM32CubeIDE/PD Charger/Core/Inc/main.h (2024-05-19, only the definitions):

#define Reg_EN_Pin GPIO_PIN_13
#define Reg_EN_GPIO_Port GPIOC
#define Vinsense_Pin GPIO_PIN_0
#define Vinsense_GPIO_Port GPIOA
#define Voutsense_Pin GPIO_PIN_1
#define Voutsense_GPIO_Port GPIOA
#define Vctrlv_Pin GPIO_PIN_2
#define Vctrlv_GPIO_Port GPIOA
#define Vadj_Pin GPIO_PIN_3
#define Vadj_GPIO_Port GPIOA
#define Vctrli_Pin GPIO_PIN_4
#define Vctrli_GPIO_Port GPIOA
#define UVLO_Pin GPIO_PIN_5
#define UVLO_GPIO_Port GPIOA
#define VadjA6_Pin GPIO_PIN_6
#define VadjA6_GPIO_Port GPIOA
#define VadjA7_Pin GPIO_PIN_7
#define VadjA7_GPIO_Port GPIOA
#define SYNC_Pin GPIO_PIN_0
#define SYNC_GPIO_Port GPIOB
#define ISmon_Pin GPIO_PIN_1
#define ISmon_GPIO_Port GPIOB
#define ISmonB2_Pin GPIO_PIN_2
#define ISmonB2_GPIO_Port GPIOB
#define I2C2_INT_Pin GPIO_PIN_10
#define I2C2_INT_GPIO_Port GPIOA
#define Discharge_Pin GPIO_PIN_10
#define Discharge_GPIO_Port GPIOC
#define Enable_Pin GPIO_PIN_11
#define Enable_GPIO_Port GPIOC

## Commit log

2024-04-13 file cleanup
    [3v3_Regulator.kicad_sch, Power_Core.kicad_sch, Processor.kicad_sch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]
2024-04-13 values updated
    [PD Charger.kicad_sch]
2024-04-15 DRC cleanup and added 3D models
    [PD Charger.kicad_pcb, PD Charger.kicad_sch]
2024-04-26 export for production
    [PD Charger-B_Cu.gbr, PD Charger-B_Mask.gbr, PD Charger-B_Paste.gbr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]
2024-04-29 silkscreen and testpoints
    [PD Charger-B_Cu.gbr, PD Charger-B_Mask.gbr, PD Charger-B_Paste.gbr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]
2024-04-29 input fuse
    [PD Charger-B_Cu.gbr, PD Charger-B_Mask.gbr, PD Charger-B_Paste.gbr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]
2024-05-13 Updated file architecture
    KiCad and STM32CubeIDE project files combined to the same repository for lockstep version control
    [PD Charger-B_Cu.gbr, PD Charger-B_Mask.gbr, PD Charger-B_Paste.gbr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]
2024-05-16 board update from tested issues
    [PD Charger.kicad_pcb, PD Charger.kicad_sch]
2024-05-19 board update
    [PD Charger.kicad_pcb, PD Charger.kicad_sch]
2024-05-19 board images
2024-05-21 better usbc & fusb302 routing
    [PD Charger.kicad_pcb, PD Charger.kicad_sch]
2024-07-22 multisheet design
    [3v3_regulator.kicad_sch, PD Charger.kicad_sch, dc-dc.kicad_sch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]
2024-09-12 new layout
    [3v3_regulator.kicad_sch, PD Charger.kicad_pcb, PD Charger.kicad_sch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]
2024-11-08 multi sheet redesign
    [PD Charger.kicad_pcb, PD Charger.kicad_sch, dc-dc.kicad_sch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]
2024-12-06 standalone regulator core
    [3v3_regulator.kicad_sch, 5V_regulator.kicad_sch, D0001.step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]
2024-12-06 3d models updated
    [PD Charger.kicad_pcb, PD Charger.kicad_sch]
2024-12-12 finishing touches
    [PD Charger.kicad_pcb]
2025-01-07 production files
    [Configuration_2024_12_30_MB1367-COM7_0.txt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]

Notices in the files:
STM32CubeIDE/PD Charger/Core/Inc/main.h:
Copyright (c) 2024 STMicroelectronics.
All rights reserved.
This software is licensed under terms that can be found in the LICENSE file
